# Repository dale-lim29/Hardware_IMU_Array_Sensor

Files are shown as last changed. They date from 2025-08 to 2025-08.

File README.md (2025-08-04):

# 16x IMU Sensor Board
This board based on use IMU sensor (ICM42688-P) and Multiplexer (TCA9548A)

## IMU Array Sensor Block Diagram

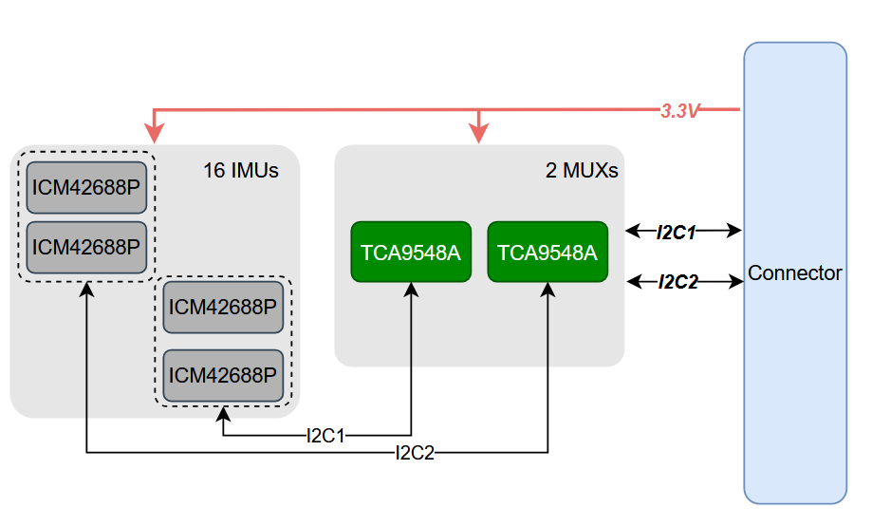
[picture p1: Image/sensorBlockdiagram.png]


## IMU Array Sensor Structure

The PCB is designed with a 6-layer stackup:

This multi-layer design ensures proper signal integrity, power distribution, and electromagnetic compatibility for the IMU array sensor system.

### PCB Design Overview

**Complete PCB Layout:**
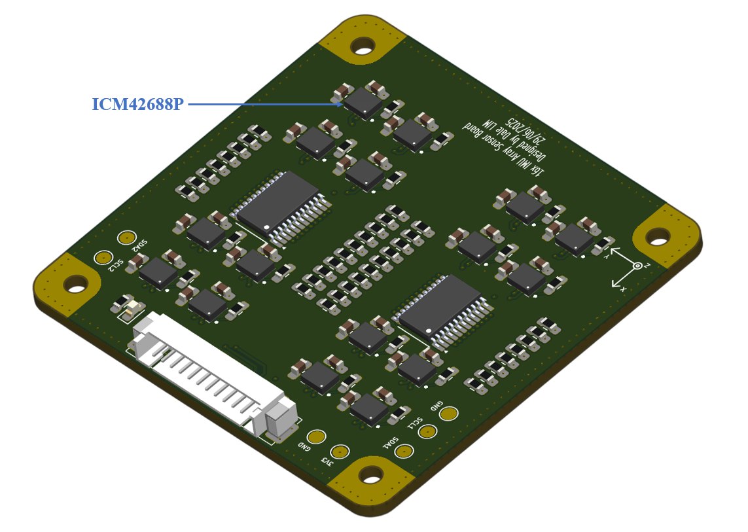
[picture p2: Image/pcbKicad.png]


### PCB Layer Images

**Layer 1:**
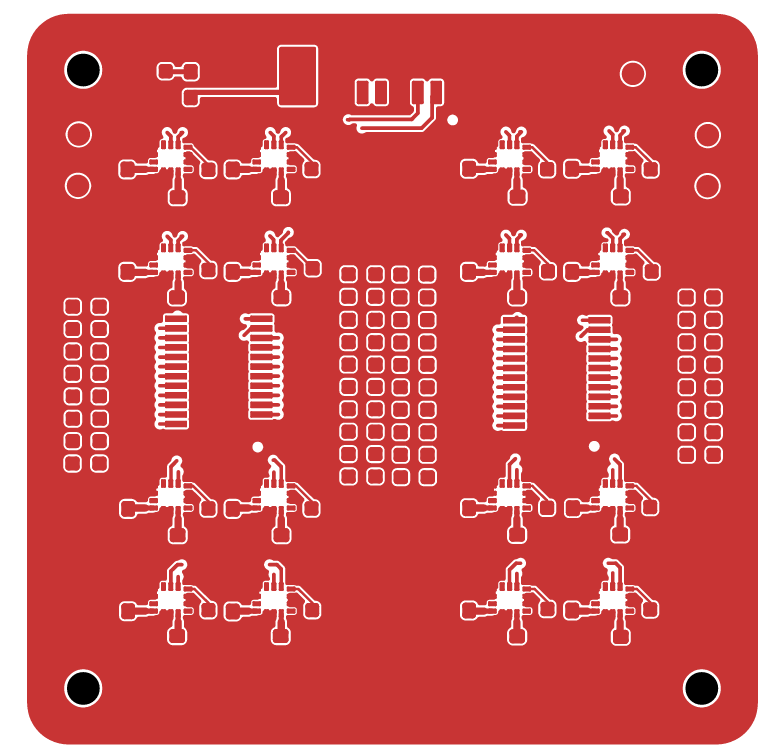
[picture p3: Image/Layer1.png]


**Layer 3:**
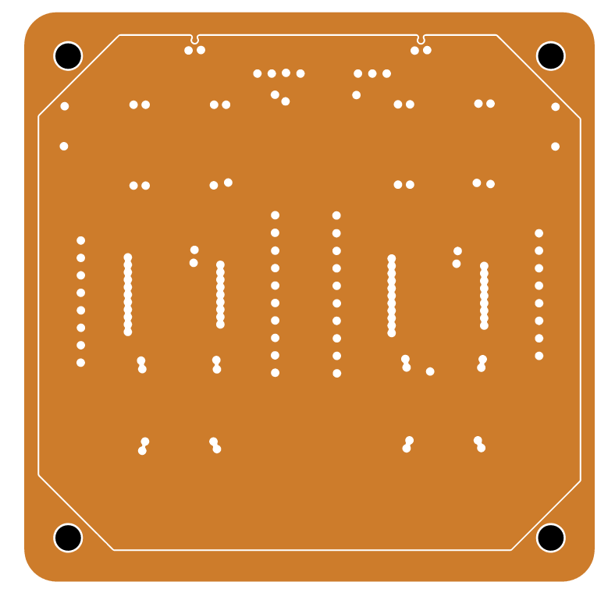
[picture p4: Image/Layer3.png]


**Layer 4:**
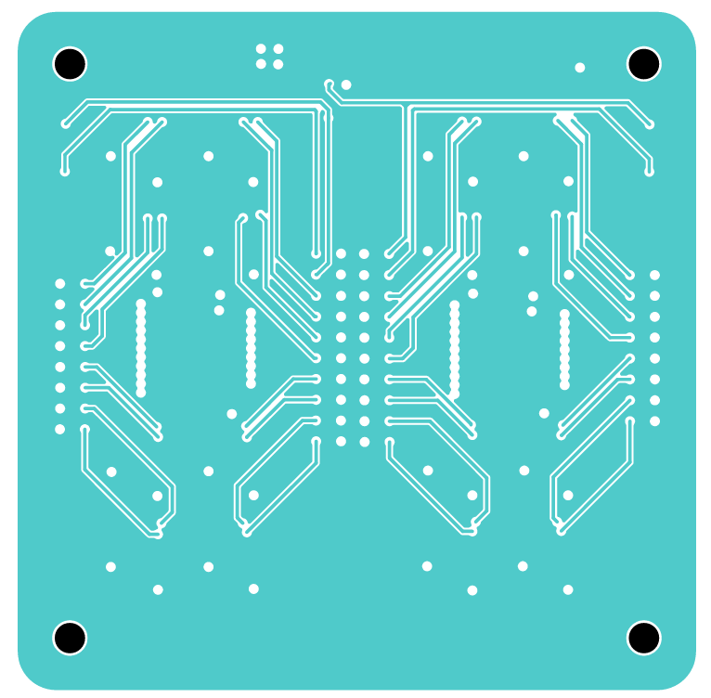
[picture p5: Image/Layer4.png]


**Layer 6:**
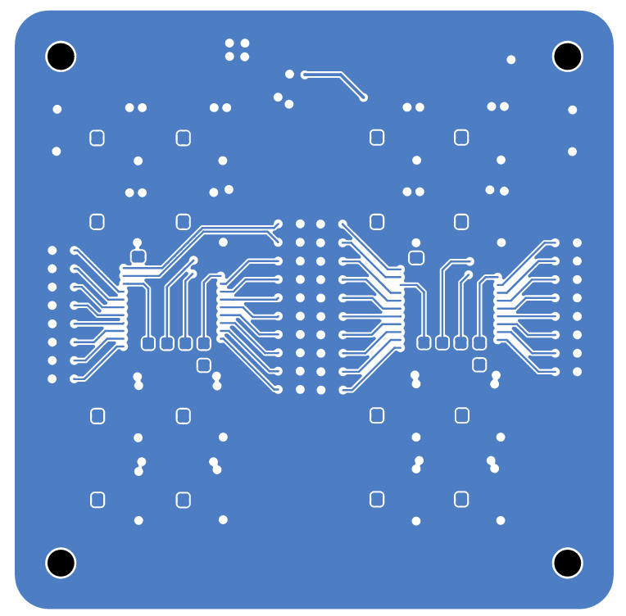
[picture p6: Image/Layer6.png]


## Note

## Firmware Check

To verify the hardware connectivity of the IMU array sensor board, upload the provided firmware to your STM32 microcontroller:

- **Binary file**: `fimware_check/STM32F401.bin`
- **Hex file**: `fimware_check/STM32F401.hex`

Upload either the `.bin` or `.hex` file to your STM32F401 microcontroller to test and validate the hardware connectivity of all IMU sensors in the array. This firmware will help you verify that:
- All IMU sensors are properly connected
- The I2C multiplexer (TCA9548A) is functioning correctly
- Communication with each sensor channel is working as expected

### Expected Output

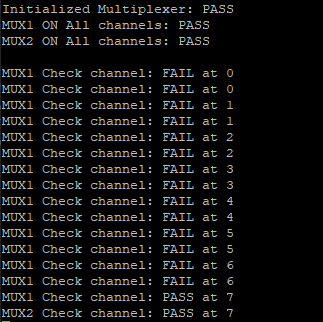
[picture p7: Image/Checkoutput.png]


The expected result shows channel 7 of both multiplexers working correctly with sensors at address 0x68, demonstrating proper hardware connectivity and communication with the IMU array.

## References

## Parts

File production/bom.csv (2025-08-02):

Designator | Footprint | Quantity | Value | LCSC Part #
C1, C12, C15, C16, C17, C18, C2, C27, C28, C29, C3, C30, C39, C40, C41, C42, C6, C9 | 0603 | 18 | 100nF | C1591
C10, C13, C19, C20, C21, C22, C31, C32, C33, C34, C4, C43, C44, C45, C46, C7 | 0603 | 16 | 10nF | C1589
C11, C14, C23, C24, C25, C26, C35, C36, C37, C38, C47, C48, C49, C5, C50, C8 | 0603 | 16 | 2.2uF | C23630
D2 | 0603 | 1 | RED | C965799
H1, H2, H3, H4 | MountingHole_2.2mm_M2 | 4 | MountingHole
J1 | 1.25-12P WT | 1 | Conn_01x14
R1, R14, R15, R17, R18, R2, R20, R21, R23, R24, R26, R27, R28, R29, R3, R30, R31, R32, R33, R38, R39, R4, R40, R41, R42, R43, R44, R45, R50, R51, R52, R53, R54, R55, R56, R57 | 0603 | 36 | 4.7k | C99782
R10, R11, R12, R16, R19, R22, R25, R34, R35, R36, R37, R46, R47, R48, R49, R58, R59, R60, R61, R62, R63, R7, R8, R9 | 0603 | 24 | 10k | C98220
R13 | 0603 | 1 | 1k | C22548
TP3, TP4, TP5, TP6, TP7, TP8, TP9 | TestPoint_Pad_D1.5mm | 7 | TestPoint
U1, U2 | TSSOP24_1.2mm | 2 | TCA9548APWR | C130026
U10, U11, U12, U13, U14, U15, U16, U17, U18, U3, U4, U5, U6, U7, U8, U9 | PQFN50P300X250X97 | 16 | ICM-42688-P | C1850418

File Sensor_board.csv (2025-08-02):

Reference | Qty | Value | DNP | Exclude from BOM | Exclude from Board | JLCPCB Part #
J1 | 1 | Conn_01x14 |  |  |  | C5884434
D2 | 1 | RED |  |  |  | C434445
C5,C8,C11,C14,C23,C24,C25,C26,C35,C36,C37,C38,C47,C48,C49,C50 | 16 | 2.2uF |  |  |  | C170151
U1,U2 | 2 | TCA9548APWR |  |  |  | C130026
R13 | 1 | 1k |  |  |  | C106235
R1,R2,R3,R4,R14,R15,R17,R18,R20,R21,R23,R24,R26,R27,R28,R29,R30,R31,R32,R33,R38,R39,R40,R41,R42,R43,R44,R45,R50,R51,R52,R53,R54,R55,R56,R57 | 36 | 4.7k |  |  |  | C105871
R5,R6,R7,R8,R9,R10,R11,R12,R16,R19,R22,R25,R34,R35,R36,R37,R46,R47,R48,R49,R58,R59,R60,R61 | 24 | 10k |  |  |  | C60490
C4,C7,C10,C13,C19,C20,C21,C22,C31,C32,C33,C34,C43,C44,C45,C46 | 16 | 10nF |  |  |  | C15195
C1,C2,C3,C6,C9,C12,C15,C16,C17,C18,C27,C28,C29,C30,C39,C40,C41,C42 | 18 | 100nF |  |  |  | C1525
U3,U4,U5,U6,U7,U8,U9,U10,U11,U12,U13,U14,U15,U16,U17,U18 | 16 | ICM-42688-P
TP3,TP4,TP5,TP6,TP7,TP8,TP9 | 7 | TestPoint
H1,H2,H3,H4 | 4 | MountingHole

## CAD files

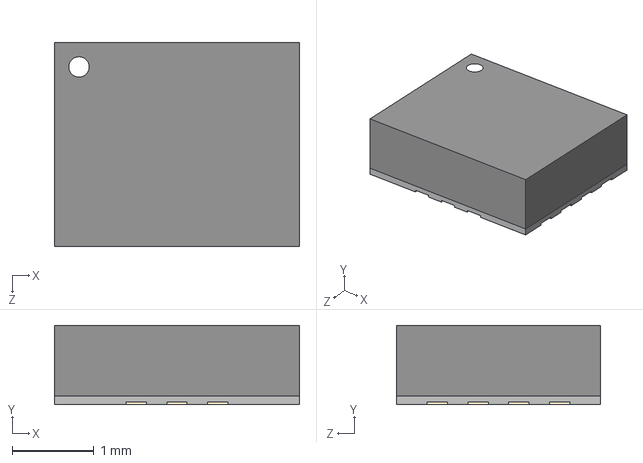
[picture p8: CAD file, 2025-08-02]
3D/ICM-42688-P.step
3.00 x 0.97 x 2.50 mm

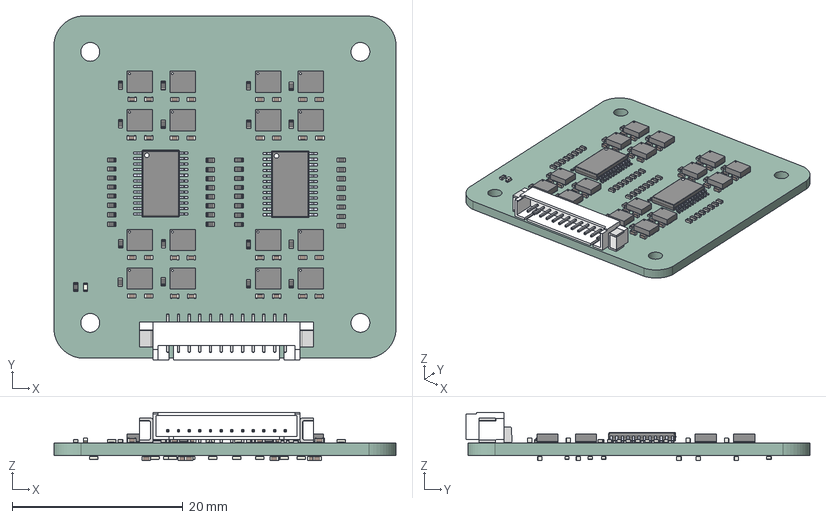
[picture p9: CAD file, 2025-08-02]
Sensor_board.step
40.0 x 40.2 x 5.66 mm
R_0402_1005Metric x 61
ICM-42688-P x 16
JST - GH - SMD (R) - 12Pin - 1.25mm
C_0402_1005Metric x 50
TCA9548APWR x 2
LED_0402_1005Metric
Sensor_board_PCB

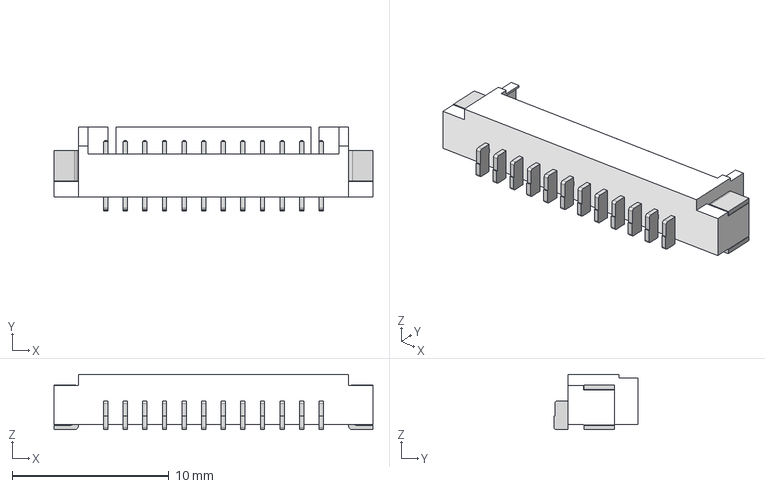
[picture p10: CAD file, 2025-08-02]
3D/JST - GH - SMD (R) - 12Pin - 1.25mm.stp
20.3 x 5.35 x 3.53 mm

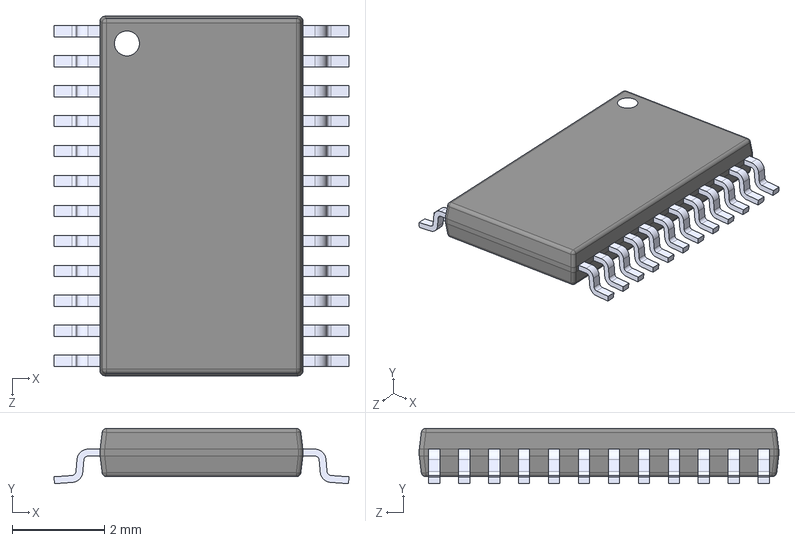
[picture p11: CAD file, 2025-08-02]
3D/TCA9548APWR.STEP
6.40 x 1.20 x 7.80 mm

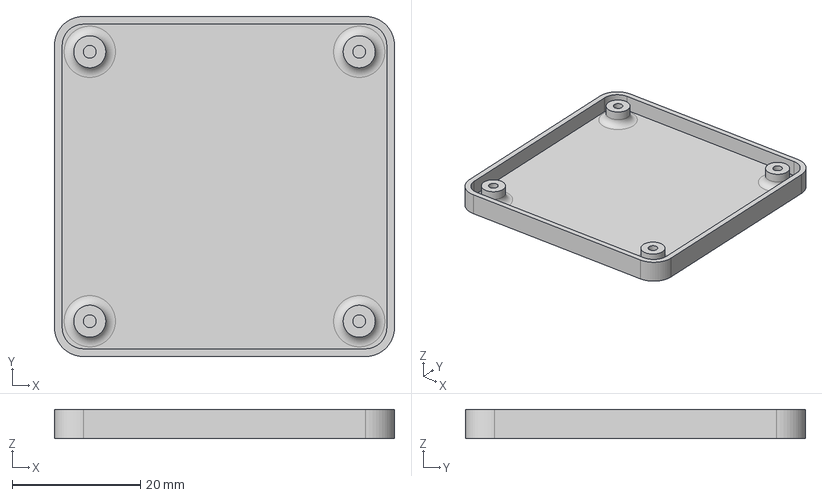
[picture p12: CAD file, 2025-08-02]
Case_IMU_Sensor v3.step
53.0 x 53.0 x 4.52 mm

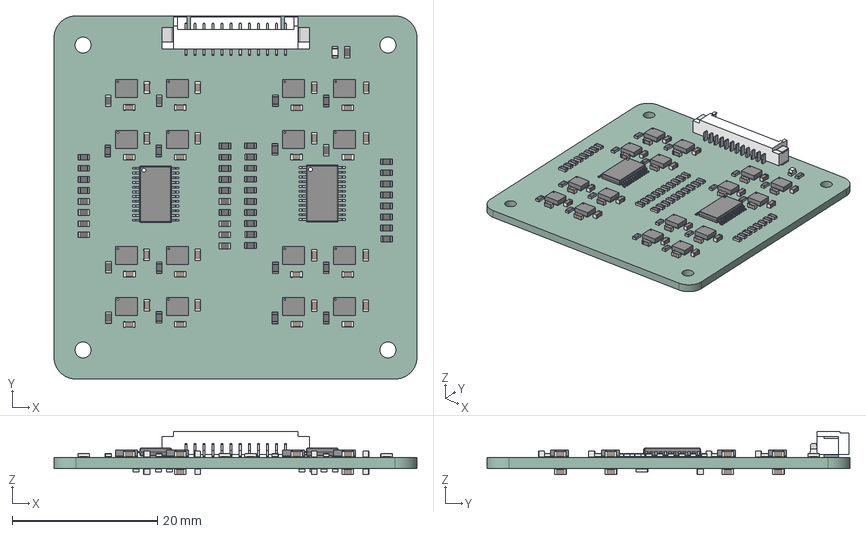
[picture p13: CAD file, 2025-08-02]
Sensor_board_v1.2.step
50.0 x 50.0 x 5.98 mm
R_0603_1608Metric x 61
ICM-42688-P x 16
JST - GH - SMD (R) - 12Pin - 1.25mm
C_0603_1608Metric x 50
TCA9548APWR x 2
LED_0603_1608Metric
Sensor_board_PCB

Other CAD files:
Sensor_case_v1.step

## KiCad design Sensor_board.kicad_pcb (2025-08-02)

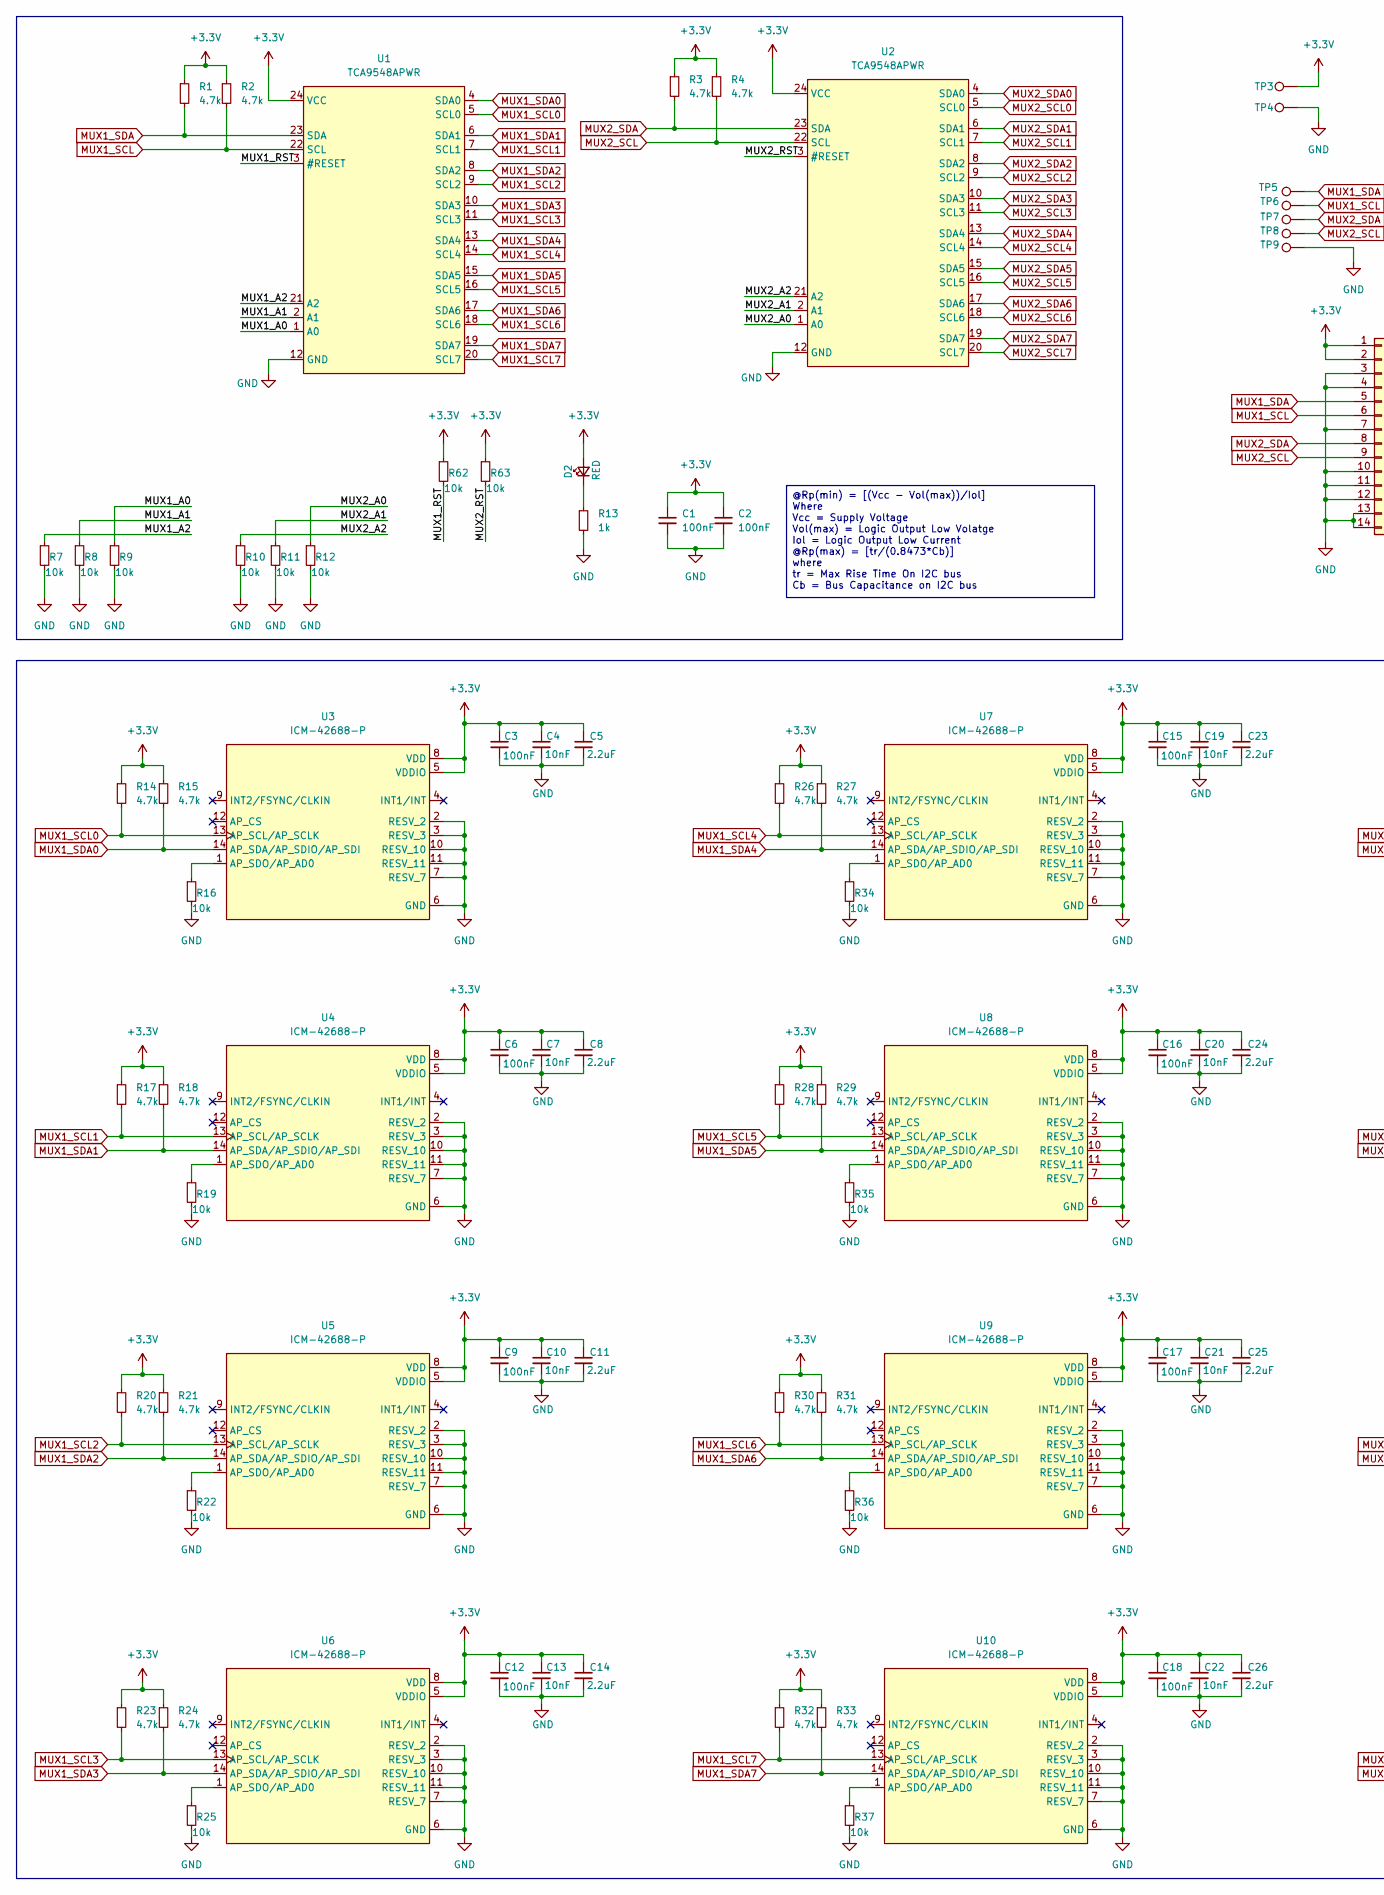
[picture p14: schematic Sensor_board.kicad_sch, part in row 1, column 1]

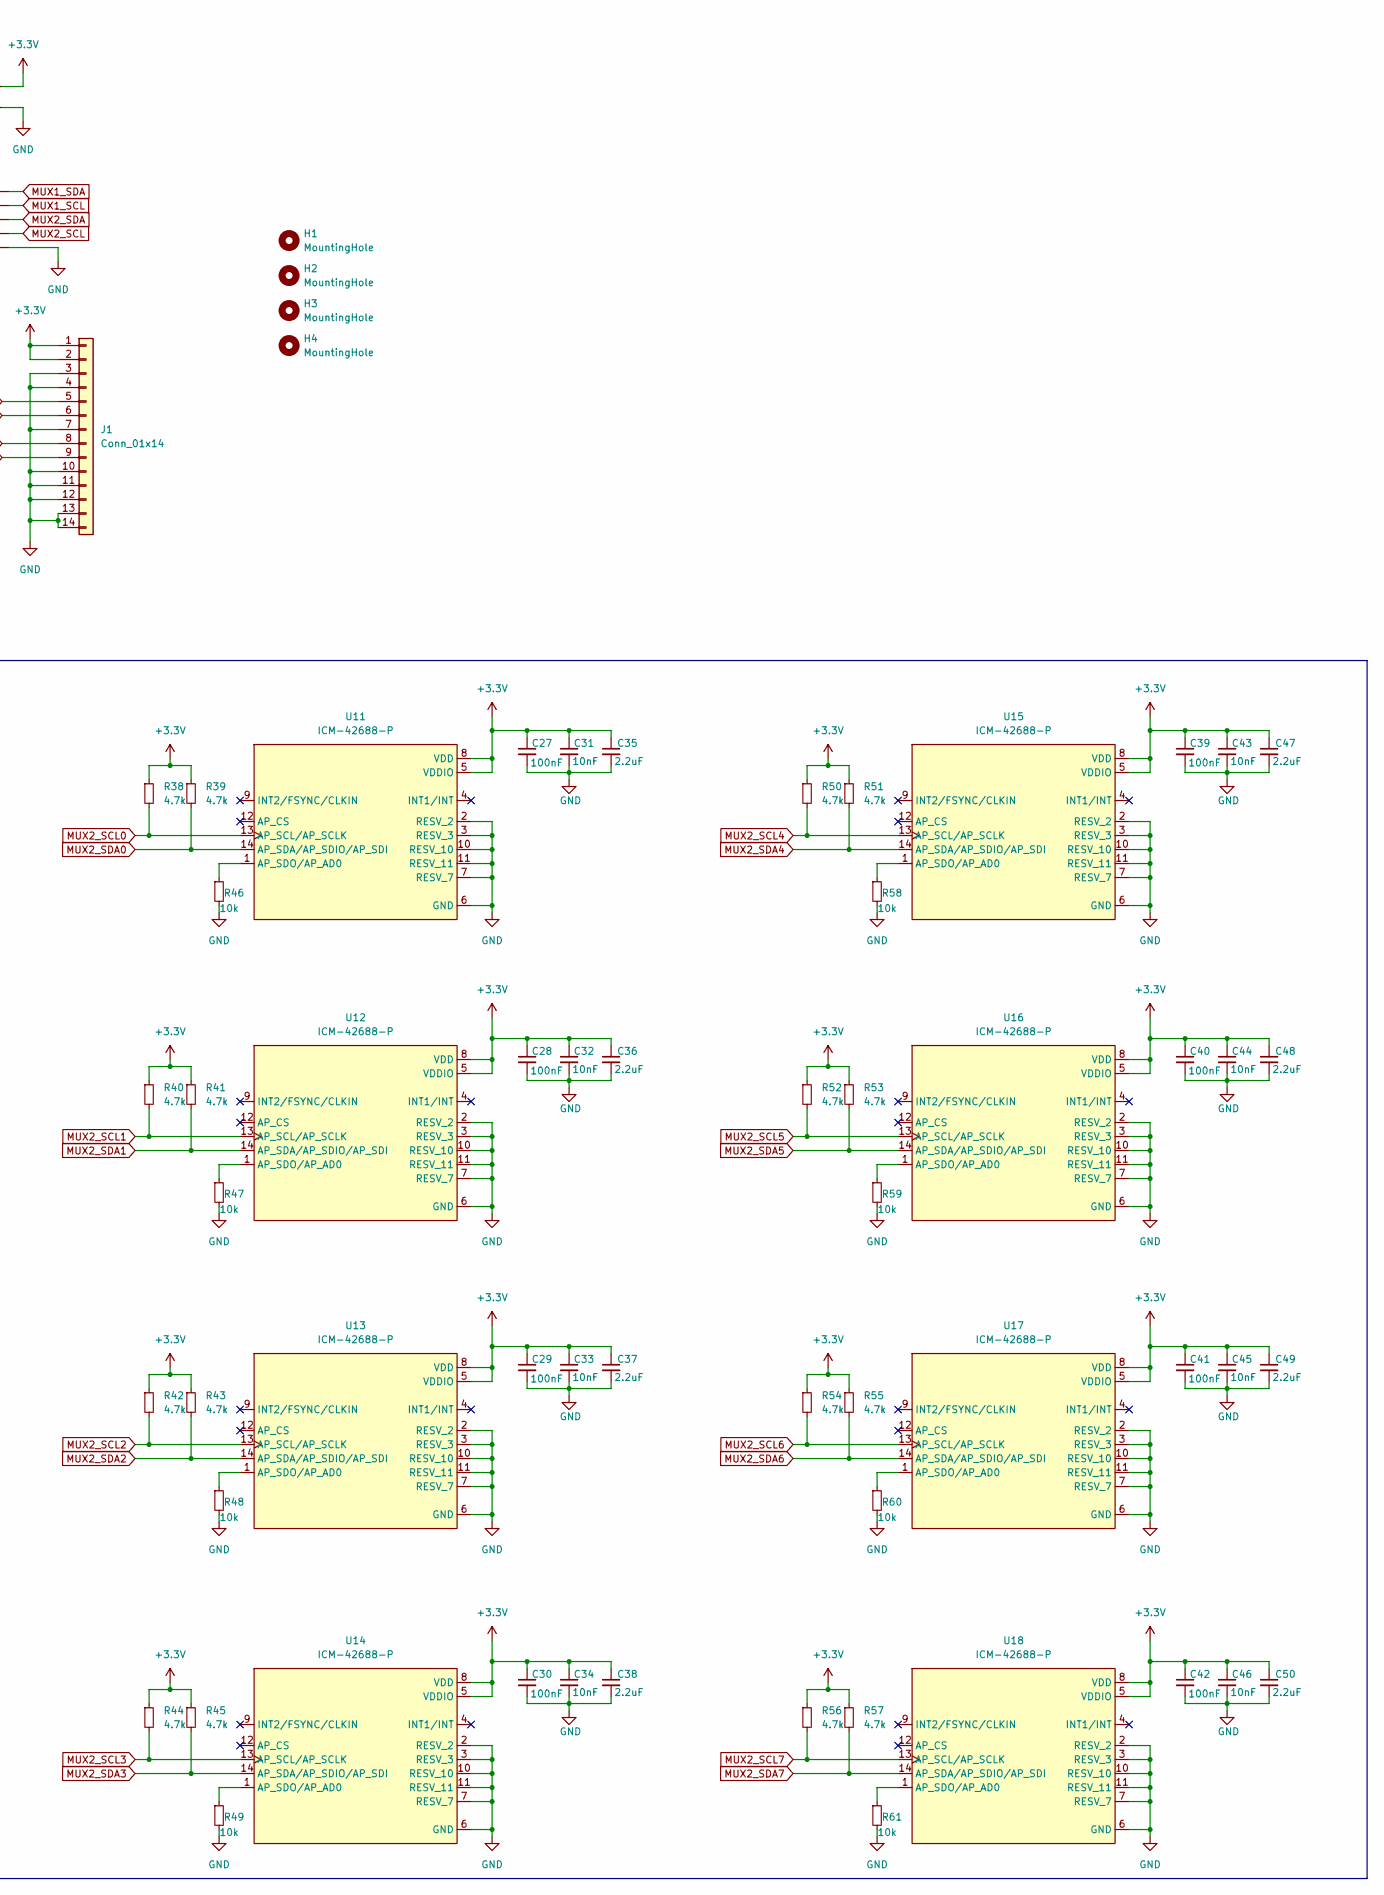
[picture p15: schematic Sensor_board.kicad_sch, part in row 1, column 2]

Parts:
C1, C2, C3, C6, C9, C12, C15, C16, C17, C18, C27, C28, C29, C30, C39, C40, C41, C42: 100nF; C_0603_1608Metric_Pad1.08x0.95mm_HandSolder; Mfr Part # CL10B104KB8NNNC; LCSC Part # C1591
C4, C7, C10, C13, C19, C20, C21, C22, C31, C32, C33, C34, C43, C44, C45, C46: 10nF; C_0603_1608Metric_Pad1.08x0.95mm_HandSolder; Mfr Part # CL10B103KB8NNNC; LCSC Part # C1589
C5, C8, C11, C14, C23, C24, C25, C26, C35, C36, C37, C38, C47, C48, C49, C50: 2.2uF; C_0603_1608Metric_Pad1.08x0.95mm_HandSolder; Mfr Part # CL10A225KO8NNNC; LCSC Part # C23630
D2: RED; LED_0603_1608Metric_Pad1.05x0.95mm_HandSolder; Mfr Part # XL-1608SURC-06; LCSC Part # C965799
H1, H2, H3, H4: MountingHole; MountingHole_2.2mm_M2
J1: Conn_01x14; 1.25-12P WT; Mfr Part # 1.25-12P WT; JLCPCB Part # C5884434
R1, R2, R3, R4, R14, R15, R17, R18, R20, R21, R23, R24, R26, R27, R28, R29, R30, R31, R32, R33, R38, R39, R40, R41, R42, R43, R44, R45, R50, R51, R52, R53, R54, R55, R56, R57: 4.7k; R_0603_1608Metric_Pad0.98x0.95mm_HandSolder; Mfr Part # RC0603FR-074K7L; LCSC Part # C99782
R7, R8, R9, R10, R11, R12, R16, R19, R22, R25, R34, R35, R36, R37, R46, R47, R48, R49, R58, R59, R60, R61, R62, R63: 10k; R_0603_1608Metric_Pad0.98x0.95mm_HandSolder; Mfr Part # RC0402FR-0710KL; LCSC Part # C98220
R13: 1k; R_0603_1608Metric_Pad0.98x0.95mm_HandSolder; Mfr Part # RC0603FR-071KL; LCSC Part # C22548
TP3, TP4, TP5, TP6, TP7, TP8, TP9: TestPoint; TestPoint_Pad_D1.5mm
U1, U2: TCA9548APWR; TSSOP24_1.2mm; Mfr Part # TCA9548APWR; LCSC Part # C130026
U3, U4, U5, U6, U7, U8, U9, U10, U11, U12, U13, U14, U15, U16, U17, U18: ICM-42688-P; PQFN50P300X250X97; Mfr Part # ICM-42688-P; LCSC Part # C1850418

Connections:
+3.3V: C1.1, C2.1, C3.1, C4.1, C5.1, C6.1, C7.1, C8.1, C9.1, C10.1, C11.1, C12.1, C13.1, C14.1, C15.1, C16.1, C17.1, C18.1, C19.1, C20.1, C21.1, C22.1, C23.1, C24.1, C25.1, C26.1, C27.1, C28.1, C29.1, C30.1, C31.1, C32.1, C33.1, C34.1, C35.1, C36.1, C37.1, C38.1, C39.1, C40.1, C41.1, C42.1, C43.1, C44.1, C45.1, C46.1, C47.1, C48.1, C49.1, C50.1, D2.2 (A), J1.1, J1.2, R1.1, R2.1, R3.1, R4.1, R14.1, R15.1, R17.1, R18.1, R20.1, R21.1, R23.1, R24.1, R26.1, R27.1, R28.1, R29.1, R30.1, R31.1, R32.1, R33.1, R38.1, R39.1, R40.1, R41.1, R42.1, R43.1, R44.1, R45.1, R50.1, R51.1, R52.1, R53.1, R54.1, R55.1, R56.1, R57.1, R62.1, R63.1, TP3.1, U1.24 (VCC), U2.24 (VCC), U3.5 (VDDIO), U3.8 (VDD), U4.5 (VDDIO), U4.8 (VDD), U5.5 (VDDIO), U5.8 (VDD), U6.5 (VDDIO), U6.8 (VDD), U7.5 (VDDIO), U7.8 (VDD), U8.5 (VDDIO), U8.8 (VDD), U9.5 (VDDIO), U9.8 (VDD), U10.5 (VDDIO), U10.8 (VDD), U11.5 (VDDIO), U11.8 (VDD), U12.5 (VDDIO), U12.8 (VDD), U13.5 (VDDIO), U13.8 (VDD), U14.5 (VDDIO), U14.8 (VDD), U15.5 (VDDIO), U15.8 (VDD), U16.5 (VDDIO), U16.8 (VDD), U17.5 (VDDIO), U17.8 (VDD), U18.5 (VDDIO), U18.8 (VDD)
/MUX1_A0: R9.1, U1.1 (A0)
/MUX1_A1: R8.1, U1.2 (A1)
/MUX1_A2: R7.1, U1.21 (A2)
/MUX1_RST: R62.2, U1.3 (#RESET)
/MUX2_A0: R12.1, U2.1 (A0)
/MUX2_A1: R11.1, U2.2 (A1)
/MUX2_A2: R10.1, U2.21 (A2)
/MUX2_RST: R63.2, U2.3 (#RESET)
GND: C1.2, C2.2, C3.2, C4.2, C5.2, C6.2, C7.2, C8.2, C9.2, C10.2, C11.2, C12.2, C13.2, C14.2, C15.2, C16.2, C17.2, C18.2, C19.2, C20.2, C21.2, C22.2, C23.2, C24.2, C25.2, C26.2, C27.2, C28.2, C29.2, C30.2, C31.2, C32.2, C33.2, C34.2, C35.2, C36.2, C37.2, C38.2, C39.2, C40.2, C41.2, C42.2, C43.2, C44.2, C45.2, C46.2, C47.2, C48.2, C49.2, C50.2, J1.3, J1.4, J1.7, J1.10, J1.11, J1.12, J1.13, J1.14, R7.2, R8.2, R9.2, R10.2, R11.2, R12.2, R13.2, R16.2, R19.2, R22.2, R25.2, R34.2, R35.2, R36.2, R37.2, R46.2, R47.2, R48.2, R49.2, R58.2, R59.2, R60.2, R61.2, TP4.1, TP9.1, U1.12 (GND), U2.12 (GND), U3.2 (RESV_2), U3.3 (RESV_3), U3.6 (GND), U3.7 (RESV_7), U3.10 (RESV_10), U3.11 (RESV_11), U4.2 (RESV_2), U4.3 (RESV_3), U4.6 (GND), U4.7 (RESV_7), U4.10 (RESV_10), U4.11 (RESV_11), U5.2 (RESV_2), U5.3 (RESV_3), U5.6 (GND), U5.7 (RESV_7), U5.10 (RESV_10), U5.11 (RESV_11), U6.2 (RESV_2), U6.3 (RESV_3), U6.6 (GND), U6.7 (RESV_7), U6.10 (RESV_10), U6.11 (RESV_11), U7.2 (RESV_2), U7.3 (RESV_3), U7.6 (GND), U7.7 (RESV_7), U7.10 (RESV_10), U7.11 (RESV_11), U8.2 (RESV_2), U8.3 (RESV_3), U8.6 (GND), U8.7 (RESV_7), U8.10 (RESV_10), U8.11 (RESV_11), U9.2 (RESV_2), U9.3 (RESV_3), U9.6 (GND), U9.7 (RESV_7), U9.10 (RESV_10), U9.11 (RESV_11), U10.2 (RESV_2), U10.3 (RESV_3), U10.6 (GND), U10.7 (RESV_7), U10.10 (RESV_10), U10.11 (RESV_11), U11.2 (RESV_2), U11.3 (RESV_3), U11.6 (GND), U11.7 (RESV_7), U11.10 (RESV_10), U11.11 (RESV_11), U12.2 (RESV_2), U12.3 (RESV_3), U12.6 (GND), U12.7 (RESV_7), U12.10 (RESV_10), U12.11 (RESV_11), U13.2 (RESV_2), U13.3 (RESV_3), U13.6 (GND), U13.7 (RESV_7), U13.10 (RESV_10), U13.11 (RESV_11), U14.2 (RESV_2), U14.3 (RESV_3), U14.6 (GND), U14.7 (RESV_7), U14.10 (RESV_10), U14.11 (RESV_11), U15.2 (RESV_2), U15.3 (RESV_3), U15.6 (GND), U15.7 (RESV_7), U15.10 (RESV_10), U15.11 (RESV_11), U16.2 (RESV_2), U16.3 (RESV_3), U16.6 (GND), U16.7 (RESV_7), U16.10 (RESV_10), U16.11 (RESV_11), U17.2 (RESV_2), U17.3 (RESV_3), U17.6 (GND), U17.7 (RESV_7), U17.10 (RESV_10), U17.11 (RESV_11), U18.2 (RESV_2), U18.3 (RESV_3), U18.6 (GND), U18.7 (RESV_7), U18.10 (RESV_10), U18.11 (RESV_11)
MUX1_SCL: J1.6, R2.2, TP6.1, U1.22 (SCL)
MUX1_SCL0: R14.2, U1.5 (SCL0), U3.13 (AP_SCL/AP_SCLK)
MUX1_SCL1: R17.2, U1.7 (SCL1), U4.13 (AP_SCL/AP_SCLK)
MUX1_SCL2: R20.2, U1.9 (SCL2), U5.13 (AP_SCL/AP_SCLK)
MUX1_SCL3: R23.2, U1.11 (SCL3), U6.13 (AP_SCL/AP_SCLK)
MUX1_SCL4: R26.2, U1.14 (SCL4), U7.13 (AP_SCL/AP_SCLK)
MUX1_SCL5: R28.2, U1.16 (SCL5), U8.13 (AP_SCL/AP_SCLK)
MUX1_SCL6: R30.2, U1.18 (SCL6), U9.13 (AP_SCL/AP_SCLK)
MUX1_SCL7: R32.2, U1.20 (SCL7), U10.13 (AP_SCL/AP_SCLK)
MUX1_SDA: J1.5, R1.2, TP5.1, U1.23 (SDA)
MUX1_SDA0: R15.2, U1.4 (SDA0), U3.14 (AP_SDA/AP_SDIO/AP_SDI)
MUX1_SDA1: R18.2, U1.6 (SDA1), U4.14 (AP_SDA/AP_SDIO/AP_SDI)
MUX1_SDA2: R21.2, U1.8 (SDA2), U5.14 (AP_SDA/AP_SDIO/AP_SDI)
MUX1_SDA3: R24.2, U1.10 (SDA3), U6.14 (AP_SDA/AP_SDIO/AP_SDI)
MUX1_SDA4: R27.2, U1.13 (SDA4), U7.14 (AP_SDA/AP_SDIO/AP_SDI)
MUX1_SDA5: R29.2, U1.15 (SDA5), U8.14 (AP_SDA/AP_SDIO/AP_SDI)
MUX1_SDA6: R31.2, U1.17 (SDA6), U9.14 (AP_SDA/AP_SDIO/AP_SDI)
MUX1_SDA7: R33.2, U1.19 (SDA7), U10.14 (AP_SDA/AP_SDIO/AP_SDI)
MUX2_SCL: J1.9, R4.2, TP8.1, U2.22 (SCL)
MUX2_SCL0: R38.2, U2.5 (SCL0), U11.13 (AP_SCL/AP_SCLK)
MUX2_SCL1: R40.2, U2.7 (SCL1), U12.13 (AP_SCL/AP_SCLK)
MUX2_SCL2: R42.2, U2.9 (SCL2), U13.13 (AP_SCL/AP_SCLK)
MUX2_SCL3: R44.2, U2.11 (SCL3), U14.13 (AP_SCL/AP_SCLK)
MUX2_SCL4: R50.2, U2.14 (SCL4), U15.13 (AP_SCL/AP_SCLK)
MUX2_SCL5: R52.2, U2.16 (SCL5), U16.13 (AP_SCL/AP_SCLK)
MUX2_SCL6: R54.2, U2.18 (SCL6), U17.13 (AP_SCL/AP_SCLK)
MUX2_SCL7: R56.2, U2.20 (SCL7), U18.13 (AP_SCL/AP_SCLK)
MUX2_SDA: J1.8, R3.2, TP7.1, U2.23 (SDA)
MUX2_SDA0: R39.2, U2.4 (SDA0), U11.14 (AP_SDA/AP_SDIO/AP_SDI)
MUX2_SDA1: R41.2, U2.6 (SDA1), U12.14 (AP_SDA/AP_SDIO/AP_SDI)
MUX2_SDA2: R43.2, U2.8 (SDA2), U13.14 (AP_SDA/AP_SDIO/AP_SDI)
MUX2_SDA3: R45.2, U2.10 (SDA3), U14.14 (AP_SDA/AP_SDIO/AP_SDI)
MUX2_SDA4: R51.2, U2.13 (SDA4), U15.14 (AP_SDA/AP_SDIO/AP_SDI)
MUX2_SDA5: R53.2, U2.15 (SDA5), U16.14 (AP_SDA/AP_SDIO/AP_SDI)
MUX2_SDA6: R55.2, U2.17 (SDA6), U17.14 (AP_SDA/AP_SDIO/AP_SDI)
MUX2_SDA7: R57.2, U2.19 (SDA7), U18.14 (AP_SDA/AP_SDIO/AP_SDI)
unnamed: D2.1 (K), R13.1
unnamed: R16.1, U3.1 (AP_SDO/AP_AD0)
unnamed: R19.1, U4.1 (AP_SDO/AP_AD0)
unnamed: R22.1, U5.1 (AP_SDO/AP_AD0)
unnamed: R25.1, U6.1 (AP_SDO/AP_AD0)
unnamed: R34.1, U7.1 (AP_SDO/AP_AD0)
unnamed: R35.1, U8.1 (AP_SDO/AP_AD0)
unnamed: R36.1, U9.1 (AP_SDO/AP_AD0)
unnamed: R37.1, U10.1 (AP_SDO/AP_AD0)
unnamed: R46.1, U11.1 (AP_SDO/AP_AD0)
unnamed: R47.1, U12.1 (AP_SDO/AP_AD0)
unnamed: R48.1, U13.1 (AP_SDO/AP_AD0)
unnamed: R49.1, U14.1 (AP_SDO/AP_AD0)
unnamed: R58.1, U15.1 (AP_SDO/AP_AD0)
unnamed: R59.1, U16.1 (AP_SDO/AP_AD0)
unnamed: R60.1, U17.1 (AP_SDO/AP_AD0)
unnamed: R61.1, U18.1 (AP_SDO/AP_AD0)

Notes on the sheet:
@Rp(min) = [(Vcc - Vol(max))/Iol] Where Vcc = Supply Voltage Vol(max) = Logic Output Low Volatge Iol = Logic Output Low Current @Rp(max) = [tr/(0.8473*Cb)] where tr = Max Rise Time On I2C bus Cb = Bus Capacitance on I2C bus

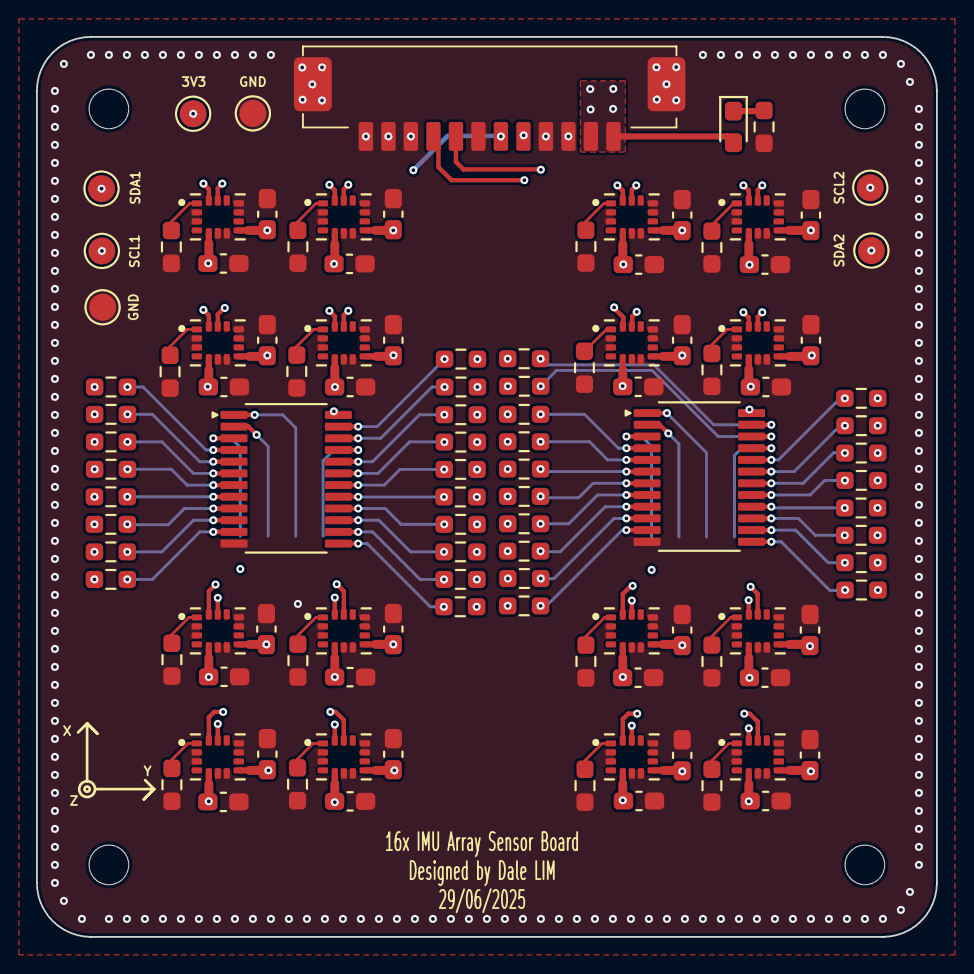
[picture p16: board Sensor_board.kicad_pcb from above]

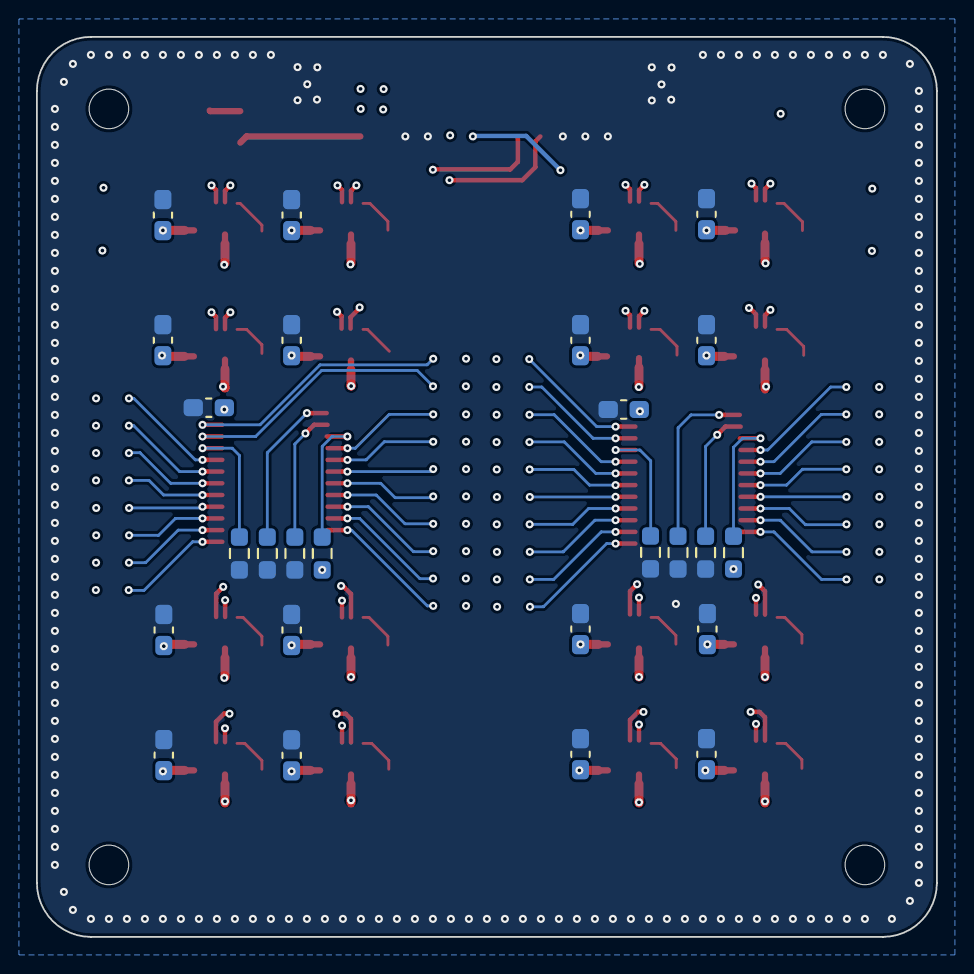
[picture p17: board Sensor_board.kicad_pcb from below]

Board: 6 copper layers, 50.0 x 50.0 mm, 142 parts (26 on the bottom side), 63 nets.
